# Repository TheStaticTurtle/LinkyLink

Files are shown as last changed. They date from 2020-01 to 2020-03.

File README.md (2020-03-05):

Everyone want's to see how much power you are actually using, This product is a wireless adapter for the french energy meter (Linky). It's based on an esp8266 which convert the raw data coming from the tele-info port on the linky and displays it in a web page. It also exposes an API for easy integration with a smart home dashboard like home-assistant.

## Disclaimer
- If you don't wire it up correctly or break anything I'm not responsible for any damage that might occur.
- Moreover, you will need a separate power source, unfortunately the alimentation loop isn't powerful enough
## The product
See the datasheet for the installation manual
#### Why did I make it?
I'm a student in computer sciences so I was interested to see how I could decode it and make it more understandable for less technical people and at the same time improve my electrical engineering skill.

#### What makes it special?
It's small and wireless, not everyone wants a big cable running from their meter to their home automation server. It has a beautiful interface:
Phone interface
Tablet interface

It's very easy to set up, just connect it to the linky, power it up, connect to its wifi enter the connection detail to your wifi and voila.
**But most importantly it's realtime no waiting for the values to change and you don't have to send all your information to enedis/edf**

#### What's included
Depending on the options you will get the board and a case and ~30cm of cable to connect it to the linky

#### Support
If you need support (eg. firmware update/error) just send me an email at tuglersamuel@gmail.com

- Hardware License: CERN v 1.2
- Software License: GPL v3
- Documentation License: CC BY

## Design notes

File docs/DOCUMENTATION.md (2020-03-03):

# A bit of context.
Linky energy meter
Teleinfo port

The Linky energy meter is "connected" energy meter it transmit the energy consumed by their user to the energy comany (Enedis).

## The inners workings
The arrow on the second picture above show the user teleinfo port. Here the user is free to plug something like the "Linky ERL" or any device to monitor the meter.


The linky provides 3 "easy" to use ports I1 I2 and A. 
The actual data comes from the circuit I1 and I2 and you have an alimentation circuit between I1 and A. For reference P, N, P', N' are the mains connections C1 and C2 connection to a water boiler and T1 / T2 are I think for technicians and are locked.

The actual signal is a unidirectional serial connection with a 50kHz carrier. The documentation (availible at the bottom) sais that the signal is at 9600bps 7E1  but the signal is accualy 1200bps at 7E1.
Converting this signal is really simple I used the following circuit:

The linky spits out frames composed of these lines (For the one I have):
```
ADCO 341964285263
OPTARIF HC..
ISOUSC 30
HCHC 000582078
HCHP 000599002
PTEC HP..
IINST 005
IMAX 090
PAPP 01115
HHPHC A
MOTDETAT 000000
```
Here's a table to see what stands for what:



# Version 1 - Prototype
The documentation tells us how a frame is transmitted: 
First you have the char 0x02 ther for each line start 0x0A and 0x0D the the end of a line the end of a frame is signaled by the char 0x03 and a premature end of data by 0x04

```cpp
#define LINKY_START_FRAME           0x02
#define LINKY_END_FRAME             0x03
#define LINKY_START_LINE            0x0A
#define LINKY_END_LINE              0x0D
#define LINKY_END_DATA              0x04
```
As I wanted to make my module compatible with 3-phased devices I added all these in the code as well and here's my structure for holding the data:
```cpp
struct LinkyData {
  char   ADCO   [13];      //Adresse du compteur
  char   OPTARIF[ 5];      //Option tarifaire choisie
  int    ISOUSC;           //Intensité souscrite
  int    BASE;             //Index option Base
  long   HCHC;             //Index option Heures Creuses - Heures Creuses
  long   HCHP;             //Index option Heures Creuses - Heures Pleines
  long   EJPHN;            //Index option EJP - Heures Normales
  long   EJPHPM;           //Index option EJP - Heures de Pointe Mobile
  long   BBRHCJB;          //Index option Tempo - Heures Creuses Jours Bleus
  long   BBRHPJB;          //Index option Tempo - Heures Pleines Jours Bleus
  long   BBRHCJW;          //Index option Tempo - Heures Creuses Jours Blancs
  long   BBRHPJW;          //Index option Tempo - Heures Pleines Jours Blancs
  long   BBRHCJR;          //Index option Tempo - Heures Pleines Jours Rouges
  long   BBRHPJR;          //Index option Tempo - Heures Pleines Jours Rouges
  int    PEJP;             //Préavis Début EJP (30 min)
  char   PTEC   [ 5];      //Période Tarifaire en cours
  char   DEMAIN [ 5];      //Couleur du lendemain
  int    IINST;            //Intensité Instantanée
  int    IINST1;           //Intensité Instantanée Phase n°1 (Triphaser seulement)
  int    IINST2;           //Intensité Instantanée Phase n°2 (Triphaser seulement)
  int    IINST3;           //Intensité Instantanée Phase n°3 (Triphaser seulement)
  int    ADPS;             //Avertissement de DépassementDe Puissance Souscrite
  int    ADIR1;            //Avertissement de DépassementDe Puissance Souscrite Phase n°1 (Triphaser seulement)
  int    ADIR2;            //Avertissement de DépassementDe Puissance Souscrite Phase n°2 (Triphaser seulement)
  int    ADIR3;            //Avertissement de DépassementDe Puissance Souscrite Phase n°3 (Triphaser seulement)
  int    IMAX;             //Intensité maximale appelée
  int    IMAX1;            //Intensité maximale appelée Phase n°1 (Triphaser seulement)
  int    IMAX2;            //Intensité maximale appelée Phase n°2 (Triphaser seulement)
  int    IMAX3;            //Intensité maximale appelée Phase n°3 (Triphaser seulement)
  long   PMAX;             //Puissance maximale triphasée atteinte
  long   PAPP;             //Puissance apparente / Puissance apparente triphasée soutirée
  char   HHPHC;            //Horaire Heures Pleines Heures Creuses
  char   MOTDETAT[ 7];     //Mot d'état du compteur
  char   PPOT    [ 3];     //Présence des potentiels (Triphaser seulement) ("0X", X = coupures de phase phase n => bit n = 1)
}; 
```

Receiving the data is as simple as creating a new software serial with the right pins and AND the incoming byte by 0x7F to get only the 7 bits since arduino softwareserial can't stricly do 7E1 communications. Then I created a char array of the size of 100 (It will never be used completly) and incremented a variable a each valid char received to store it.

```cpp
void Linky::processRXChar(char currentChar) {
	if(currentChar == LINKY_START_FRAME) {
		memset(_buffer, 0, LINKY_BUFFER_TELEINFO_SIZE);
		_bufferIterator = 0;

	} else if(currentChar == LINKY_START_LINE) {
		memset(_buffer, 0, LINKY_BUFFER_TELEINFO_SIZE);
		_bufferIterator = 0;

	} else if(currentChar == LINKY_END_FRAME) {
		memset(_buffer, 0, LINKY_BUFFER_TELEINFO_SIZE);
		_bufferIterator = 0;

	} else if(currentChar == LINKY_END_LINE) {
		updateStruct(_bufferIterator);
		memset(_buffer, 0, LINKY_BUFFER_TELEINFO_SIZE);
		_bufferIterator = 0;

	} else if(currentChar == LINKY_END_DATA) {
		memset(_buffer, 0, LINKY_BUFFER_TELEINFO_SIZE);
		_bufferIterator = 0;

	} else {
		_buffer[_bufferIterator] = currentChar;
		_bufferIterator++;

	}
}
void Linky::updateAsync() {
	if(_serport->available()) {
		char currentChar;

		currentChar = _serport->read() & 0x7F;
		processRXChar(currentChar);
	}
}
```
Then I created a couple of function that ease the parsing of the data by a lot (getCommandValue_int / getCommandValue_long / getCommandValue_str) to use these function you have to pass the actual command name like ADCO the length in this case 4 and the expcted length of the output in this case 12 plus some other values like the size of received line.
```cpp
bool Linky::isValidNumber(String str){
   for(byte i=0;i<str.length();i++)  {
       if(!isDigit(str.charAt(i))) return false;
   }
   return true;
}

int Linky::getCommandValue_int(String CMD, int CMDlenght, int CMDResultLenght, String line, int lineLenght, int defaultIfError) {
  if(!line.startsWith(CMD)) { return defaultIfError; }
  if(CMDlenght+1+CMDResultLenght > lineLenght) { return defaultIfError; } // Invalid size line length too short
  
  String raw_value = line.substring(CMDlenght+1, CMDlenght+1+CMDResultLenght);
  if(!isValidNumber(raw_value)) { return defaultIfError; }
  
  return raw_value.toInt();
}

long Linky::getCommandValue_long(String CMD, int CMDlenght, int CMDResultLenght, String line, int lineLenght, long defaultIfError) {
  if(!line.startsWith(CMD)) { return defaultIfError; }
  if(CMDlenght+1+CMDResultLenght > lineLenght) { return defaultIfError; } // Invalid size line length too short
  
  String raw_value = line.substring(CMDlenght+1, CMDlenght+1+CMDResultLenght);
  if(!isValidNumber(raw_value)) { return defaultIfError; }
  
  return (long)raw_value.toInt();
}

bool Linky::getCommandValue_str(String CMD, int CMDlenght, int CMDResultLenght, String line, int lineLenght, char* value) {
  if(!line.startsWith(CMD)) { return false; }
  if(CMDlenght+1+CMDResultLenght > lineLenght) { return false; } // Invalid size line length too short
  
  line.substring(CMDlenght+1, CMDlenght+1+CMDResultLenght).toCharArray(value,CMDResultLenght+1);
  return true;
} 

void Linky::updateStruct(int len) {
	 getCommandValue_str ("ADCO"    , 4,12,_buffer,len+1, _data.ADCO     );
	 getCommandValue_str ("OPTARIF" , 7, 4,_buffer,len+1, _data.OPTARIF  );
	_data.ISOUSC 	=	getCommandValue_int ("ISOUSC"  , 6, 2,_buffer,len+1, _data.ISOUSC);
	_data.HCHC   	=	getCommandValue_long("HCHC"    , 4, 9,_buffer,len+1, _data.HCHC);
	_data.HCHP   	=	getCommandValue_long("HCHP"    , 4, 9,_buffer,len+1, _data.HCHP);
	_data.EJPHN  	=	getCommandValue_long("EJPHN"   , 5, 9,_buffer,len+1, _data.EJPHN);
	_data.EJPHPM 	=	getCommandValue_long("EJPHPM"  , 6, 9,_buffer,len+1, _data.EJPHPM);
	_data.BBRHCJB	=	getCommandValue_long("BBRHCJB" , 7, 9,_buffer,len+1, _data.BBRHCJB);
	_data.BBRHPJB	=	getCommandValue_long("BBRHPJB" , 7, 9,_buffer,len+1, _data.BBRHPJB);
	_data.BBRHCJW	=	getCommandValue_long("BBRHCJW" , 7, 9,_buffer,len+1, _data.BBRHCJW);
	_data.BBRHPJW	=	getCommandValue_long("BBRHPJW" , 7, 9,_buffer,len+1, _data.BBRHPJW);
	_data.BBRHCJR	=	getCommandValue_long("BBRHCJR" , 7, 9,_buffer,len+1, _data.BBRHCJR);
	_data.BBRHPJR	=	getCommandValue_long("BBRHPJR" , 7, 9,_buffer,len+1, _data.BBRHPJR);
	_data.PEJP   	=	getCommandValue_int ("PEJP"    , 4, 2,_buffer,len+1, _data.HCHP);
 	 getCommandValue_str ("PTEC"    , 4, 4,_buffer,len+1, _data.PTEC  );
     getCommandValue_str ("DEMAIN"  , 6, 4,_buffer,len+1, _data.DEMAIN  );
	_data.IINST     = 	getCommandValue_int ("IINST"   , 5, 3,_buffer,len+1, _data.IINST); 
	_data.IINST1    = 	getCommandValue_int ("IINST1"  , 6, 3,_buffer,len+1, _data.IINST1); 
	_data.IINST2    = 	getCommandValue_int ("IINST2"  , 6, 3,_buffer,len+1, _data.IINST2); 
	_data.IINST3    = 	getCommandValue_int ("IINST3"  , 6, 3,_buffer,len+1, _data.IINST3); 
	_data.ADPS      = 	getCommandValue_int ("ADPS"    , 4, 3,_buffer,len+1, _data.ADPS); 
	_data.ADIR1     = 	getCommandValue_int ("ADIR1"   , 5, 3,_buffer,len+1, _data.ADIR1); 
	_data.ADIR2     = 	getCommandValue_int ("ADIR2"   , 5, 3,_buffer,len+1, _data.ADIR2); 
	_data.ADIR3     = 	getCommandValue_int ("ADIR3"   , 5, 3,_buffer,len+1, _data.ADIR3);
	_data.IMAX      = 	getCommandValue_int ("IMAX"    , 4, 3,_buffer,len+1, _data.IMAX); 
	_data.IMAX1     = 	getCommandValue_int ("IMAX1"   , 5, 3,_buffer,len+1, _data.IMAX1); 
	_data.IMAX2     = 	getCommandValue_int ("IMAX2"   , 5, 3,_buffer,len+1, _data.IMAX2); 
	_data.IMAX3     = 	getCommandValue_int ("IMAX3"   , 5, 3,_buffer,len+1, _data.IMAX3); 
	_data.PMAX      = 	getCommandValue_long("PMAX"    , 4, 5,_buffer,len+1, _data.PMAX); 
	_data.PAPP      = 	getCommandValue_long("PAPP"    , 4, 5,_buffer,len+1, _data.PAPP); 
	 getCommandValue_str ("MOTDETAT", 8, 6,_buffer,len+1, _data.MOTDETAT );
	 getCommandValue_str ("PPOT"    , 4, 2,_buffer,len+1, _data.PPOT);
}
```

## Implementing everything into the ESP8266
**Needs writing**

## PCB Desing
**Needs writing**

## Assembly
**Needs writing**

## Finished product
**Needs writing**

## Sources:
[Enedis documentation](https://www.enedis.fr/sites/default/files/Enedis-NOI-CPT_54E.pdf)

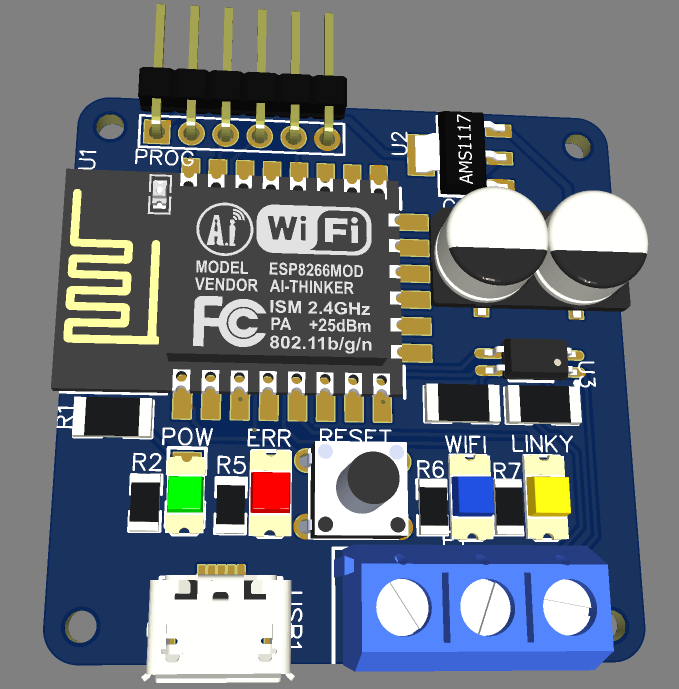
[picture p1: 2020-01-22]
hardware/renderV1.png

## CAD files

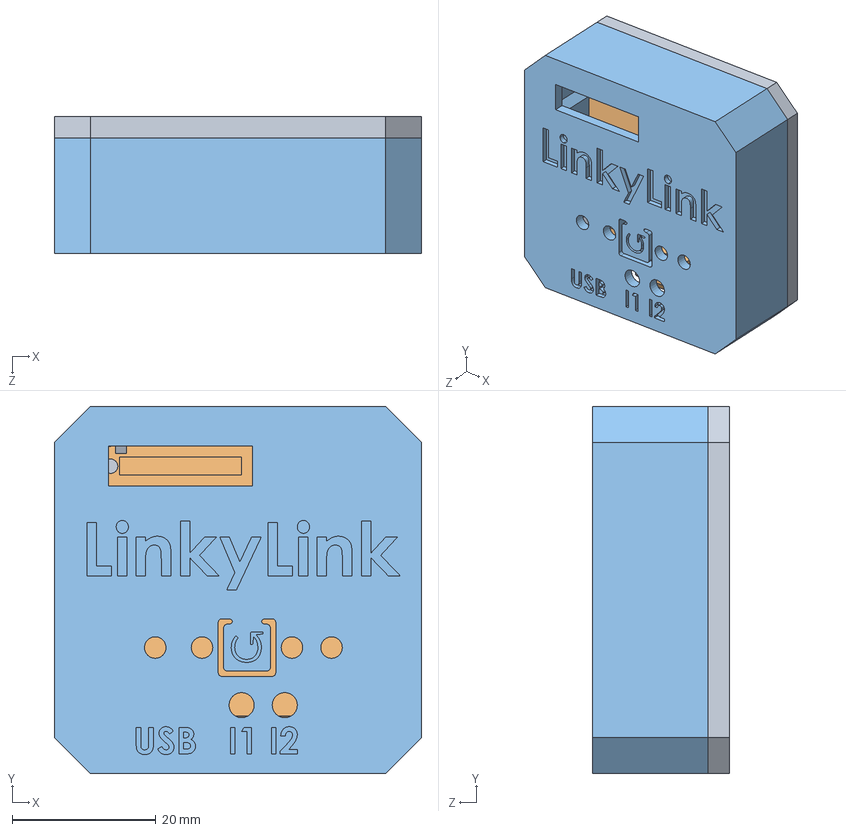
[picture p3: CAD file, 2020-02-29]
hardware/3d/Assemblage2.SLDASM
51.0 x 51.0 x 19.0 mm
basev2
pcb
Pièce5^Assemblage2

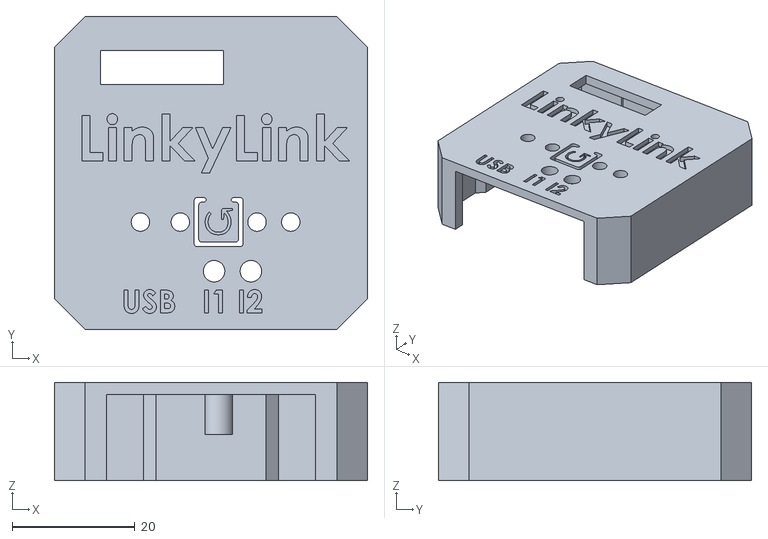
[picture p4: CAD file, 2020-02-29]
hardware/3d/Stls/Assemblage2 - Pièce5^Assemblage2-1-1.STL
51.0 x 51.0 x 16.0

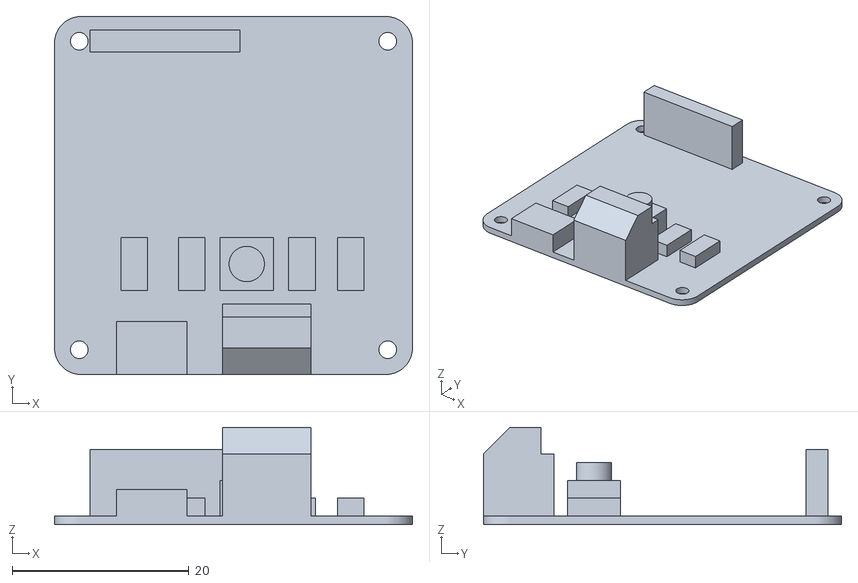
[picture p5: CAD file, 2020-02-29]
hardware/3d/Stls/Assemblage2 - pcb-1.STL
40.5 x 40.5 x 11.0

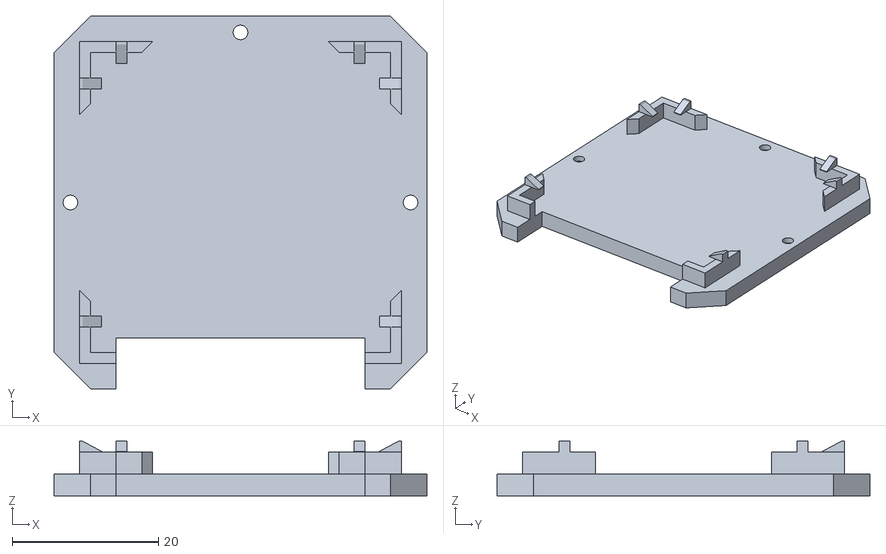
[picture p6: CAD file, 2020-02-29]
hardware/3d/Stls/Assemblage2 - basev2-1-1.STL
51.0 x 51.0 x 7.50

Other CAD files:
hardware/3d/Stls/Assemblage2 - basev2-1.STL
hardware/3d/Stls/Assemblage2 - Pièce5^Assemblage2-1.STL
hardware/3d/basev2.SLDPRT
hardware/3d/pcb.SLDPRT

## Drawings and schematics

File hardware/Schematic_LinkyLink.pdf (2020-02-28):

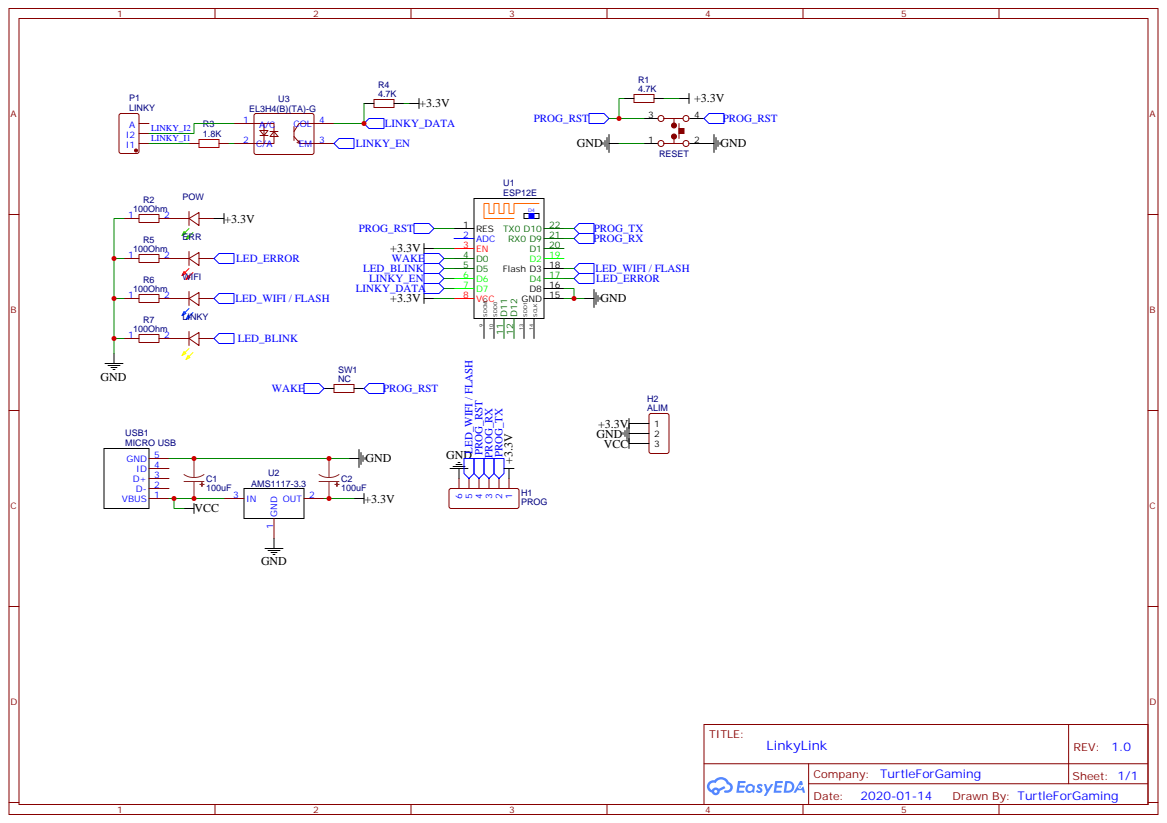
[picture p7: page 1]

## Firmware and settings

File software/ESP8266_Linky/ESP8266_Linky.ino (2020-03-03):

#include <FS.h>                   //this needs to be first, or it all crashes and burns...
#include <ESP8266WiFi.h>
#include <DNSServer.h>
#include <ESPAsyncTCP.h>
#include <ESPAsyncWebServer.h>
#include <ESPAsyncWiFiManager.h>
#include <ArduinoJson.h>
#include <ESP8266mDNS.h>
#include <ArduinoOTA.h>
#include <WiFiUdp.h>
#include <Ticker.h>
#include <SPIFFSLogger.h>

#include "linky.h"

const char* MODULE_SERIAL_NUM   = "LinkyLinky-00001";
const char* MODULE_VERSION_SOFT = "V1.0";
const char* MODULE_VERSION_HARD = "V1.0";

const int   PINS_LED_STATUS_WIFI = D3;
const int   PINS_LED_STATUS_LINK = D5;
const int   PINS_LED_STATUS_ERR  = D4;
const int   PINS_CTRL_DATA_IN    = D6;
const int   LOGGING_INTERVAL     = 10000;
const int   LOGGING_DAY_KEPT     = 1;
const char* LOGGING_FOLDER       = "/log/linkydata";

 
Linky mLinky(D7,-1,PINS_CTRL_DATA_IN);
AsyncWebServer server(80);
DNSServer dns;
Ticker tickerWifiLed;

long lastRequestCounter = 0;
bool shouldReEnableListingToLinky = false;

const size_t ApiJsonTemplate_capacity = JSON_OBJECT_SIZE(31) + 310;

struct LoggingData {
	long PAPP;
};

SPIFFSLogger<LoggingData> logger(LOGGING_FOLDER, LOGGING_DAY_KEPT);


void handleAPI_Reboot(AsyncWebServerRequest *request) {
	Serial.println("[WEB] Serving 200 for: /api/reboot");
	Serial.flush();

	AsyncResponseStream *response = request->beginResponseStream("plain/text");
	response->addHeader("Access-Control-Allow-Methods", "POST,GET,OPTIONS");
	response->addHeader("Access-Control-Allow-Headers", "Origin, X-Requested-With, Content-Type, Accept");
	response->addHeader("Access-Control-Allow-Origin", "*");
	response->printf("REBOOTING");
	request->send(response);

	ESP.restart();
	lastRequestCounter = millis();
	shouldReEnableListingToLinky = true;
}

void handleAPI_Info(AsyncWebServerRequest *request) {
	Serial.println("[WEB] Serving 200 for: /api/info");
	Serial.flush();
	AsyncResponseStream *response = request->beginResponseStream("application/json");
	response->addHeader("Access-Control-Allow-Methods", "POST,GET,OPTIONS");
	response->addHeader("Access-Control-Allow-Headers", "Origin, X-Requested-With, Content-Type, Accept");
	response->addHeader("Access-Control-Allow-Origin", "*");
	
	StaticJsonDocument<200> doc;
	doc["serial_number"]    = MODULE_SERIAL_NUM;
	doc["version_software"] = MODULE_VERSION_SOFT;
	doc["version_hardware"] = MODULE_VERSION_HARD;
	doc["uptime"]           = millis() / 1000;
	doc["lastUpdate"]       = mLinky.lastFullFrame() /1000;
	
	serializeJson(doc, *response);

	request->send(response);
	lastRequestCounter = millis();
	shouldReEnableListingToLinky = true;
}

void handleAPI_Debug(AsyncWebServerRequest *request) {
	Serial.println("[WEB] Serving 200 for: /api/debug");
	Serial.flush();
	AsyncResponseStream *response = request->beginResponseStream("application/json");
	response->addHeader("Access-Control-Allow-Methods", "POST,GET,OPTIONS");
	response->addHeader("Access-Control-Allow-Headers", "Origin, X-Requested-With, Content-Type, Accept");
	response->addHeader("Access-Control-Allow-Origin", "*");
	
	StaticJsonDocument<200> doc;
	doc["serial_number"]     = MODULE_SERIAL_NUM;
	doc["version_software"]  = MODULE_VERSION_SOFT;
	doc["version_hardware"]  = MODULE_VERSION_HARD;
	doc["uptime"]            = millis() / 1000;
	doc["lastUpdate"]        = mLinky.lastFullFrame() /1000;
	doc["wifi_status"]       = WiFi.status();
	doc["wifi_macaddr"]      = WiFi.macAddress();
	doc["free_heap"]         = ESP.getFreeHeap();
	doc["max_block_size"]    = ESP.getMaxFreeBlockSize();
	doc["last_reset_cause"]  = ESP.getResetReason();
	doc["core_version"]      = ESP.getCoreVersion();
	doc["vcc"]               = ESP.getVcc();
	
	serializeJson(doc, *response);

	request->send(response);
	lastRequestCounter = millis();
	shouldReEnableListingToLinky = true;
}

void handleAPI_Linky(AsyncWebServerRequest *request) {
	Serial.println("[WEB] Serving 200 for: /api/linky");
	Serial.flush();

	LinkyData linkyData = mLinky.grab();

	if(request->hasParam("key")) {
		AsyncWebParameter* p = request->getParam("key");
		String output = F("Key is invalid");
		if(p->value() == "ADCO"    ) { output = linkyData.ADCO;    }   
		if(p->value() == "OPTARIF" ) { output = linkyData.OPTARIF; }      
		if(p->value() == "ISOUSC"  ) { output = linkyData.ISOUSC;  }     
		if(p->value() == "HCHC"    ) { output = linkyData.HCHC;    }   
		if(p->value() == "HCHP"    ) { output = linkyData.HCHP;    }   
		if(p->value() == "EJPHN"   ) { output = linkyData.EJPHN;   }    
		if(p->value() == "EJPHPM"  ) { output = linkyData.EJPHPM;  }     
		if(p->value() == "BBRHCJB" ) { output = linkyData.BBRHCJB; }      
		if(p->value() == "BBRHPJB" ) { output = linkyData.BBRHPJB; }      
		if(p->value() == "BBRHCJW" ) { output = linkyData.BBRHCJW; }      
		if(p->value() == "BBRHPJW" ) { output = linkyData.BBRHPJW; }      
		if(p->value() == "BBRHCJR" ) { output = linkyData.BBRHCJR; }      
		if(p->value() == "BBRHPJR" ) { output = linkyData.BBRHPJR; }      
		if(p->value() == "PEJP"    ) { output = linkyData.PEJP;    }   
		if(p->value() == "PTEC"    ) { output = linkyData.PTEC;    }   
		if(p->value() == "DEMAIN"  ) { output = linkyData.DEMAIN;  }     
		if(p->value() == "IINST"   ) { output = linkyData.IINST;   }    
		if(p->value() == "IINST1"  ) { output = linkyData.IINST1;  }     
		if(p->value() == "IINST2"  ) { output = linkyData.IINST2;  }     
		if(p->value() == "IINST3"  ) { output = linkyData.IINST3;  }     
		if(p->value() == "ADPS"    ) { output = linkyData.ADPS;    }   
		if(p->value() == "ADIR1"   ) { output = linkyData.ADIR1;   }    
		if(p->value() == "ADIR2"   ) { output = linkyData.ADIR2;   }    
		if(p->value() == "ADIR3"   ) { output = linkyData.ADIR3;   }    
		if(p->value() == "IMAX"    ) { output = linkyData.IMAX;    }
		if(p->value() == "IMAX1"   ) { output = linkyData.IMAX1;   }
		if(p->value() == "IMAX2"   ) { output = linkyData.IMAX2;   }
		if(p->value() == "IMAX3"   ) { output = linkyData.IMAX3;   }    
		if(p->value() == "PMAX"    ) { output = linkyData.PMAX;    }
		if(p->value() == "PAPP"    ) { output = linkyData.PAPP;    }
		if(p->value() == "HHPHC"   ) { output = linkyData.HHPHC;   }
		if(p->value() == "MOTDETAT") { output = linkyData.MOTDETAT;   }
		if(p->value() == "PPOT"    ) { output = linkyData.PPOT;   }

		AsyncWebServerResponse *response = request->beginResponse(200,"text/plain",output);
		response->addHeader("Access-Control-Allow-Methods", "POST,GET,OPTIONS");
		response->addHeader("Access-Control-Allow-Headers", "Origin, X-Requested-With, Content-Type, Accept");
		response->addHeader("Access-Control-Allow-Origin", "*");
		request->send(response);

	} else {
		DynamicJsonDocument ApiJsonTemplate_doc(ApiJsonTemplate_capacity);
		ApiJsonTemplate_doc["ADCO"    ] = linkyData.ADCO;
		ApiJsonTemplate_doc["OPTARIF" ] = linkyData.OPTARIF;
		ApiJsonTemplate_doc["ISOUSC"  ] = linkyData.ISOUSC;
		ApiJsonTemplate_doc["HCHC"    ] = linkyData.HCHC;
		ApiJsonTemplate_doc["HCHP"    ] = linkyData.HCHP;
		ApiJsonTemplate_doc["EJPHN"   ] = linkyData.EJPHN;
		ApiJsonTemplate_doc["EJPHPM"  ] = linkyData.EJPHPM;
		ApiJsonTemplate_doc["BBRHCJB" ] = linkyData.BBRHCJB;
		ApiJsonTemplate_doc["BBRHPJB" ] = linkyData.BBRHPJB;
		ApiJsonTemplate_doc["BBRHCJW" ] = linkyData.BBRHCJW;
		ApiJsonTemplate_doc["BBRHPJW" ] = linkyData.BBRHPJW;
		ApiJsonTemplate_doc["BBRHCJR" ] = linkyData.BBRHCJR;
		ApiJsonTemplate_doc["BBRHPJR" ] = linkyData.BBRHPJR;
		ApiJsonTemplate_doc["PEJP"    ] = linkyData.PEJP;
		ApiJsonTemplate_doc["PTEC"    ] = linkyData.PTEC;
		ApiJsonTemplate_doc["DEMAIN"  ] = linkyData.DEMAIN;
		ApiJsonTemplate_doc["IINST"   ] = linkyData.IINST;
		ApiJsonTemplate_doc["IINST1"  ] = linkyData.IINST1;
		ApiJsonTemplate_doc["IINST2"  ] = linkyData.IINST2;
		ApiJsonTemplate_doc["IINST3"  ] = linkyData.IINST3;
		ApiJsonTemplate_doc["ADPS"    ] = linkyData.ADPS;
		ApiJsonTemplate_doc["ADIR1"   ] = linkyData.ADIR1;
		ApiJsonTemplate_doc["ADIR2"   ] = linkyData.ADIR2;
		ApiJsonTemplate_doc["ADIR3"   ] = linkyData.ADIR3;
		ApiJsonTemplate_doc["IMAX"    ] = linkyData.IMAX;
		ApiJsonTemplate_doc["IMAX1"   ] = linkyData.IMAX1;
		ApiJsonTemplate_doc["IMAX2"   ] = linkyData.IMAX2;
		ApiJsonTemplate_doc["IMAX3"   ] = linkyData.IMAX3;
		ApiJsonTemplate_doc["PMAX"    ] = linkyData.PMAX;
		ApiJsonTemplate_doc["PAPP"    ] = linkyData.PAPP;
		ApiJsonTemplate_doc["HHPHC"   ] = linkyData.HHPHC;
		ApiJsonTemplate_doc["MOTDETAT"] = linkyData.MOTDETAT;
		ApiJsonTemplate_doc["PPOT"    ] = linkyData.PPOT;

		AsyncResponseStream *response = request->beginResponseStream("application/json");
		response->addHeader("Access-Control-Allow-Methods", "POST,GET,OPTIONS");
		response->addHeader("Access-Control-Allow-Headers", "Origin, X-Requested-With, Content-Type, Accept");
		response->addHeader("Access-Control-Allow-Origin", "*");
		serializeJson(ApiJsonTemplate_doc, *response);
		request->send(response);
	}

	lastRequestCounter = millis();
	shouldReEnableListingToLinky = true;
}

float max(float a, float b) {
	if( a > b ) { return a; }
	return b;
}

void pathFromDate(char *output, time_t date) {
    struct tm *tinfo = gmtime(&date);
    sprintf_P(output,
              "%s/%d%02d%02d",
              "/log/linkydata",
              1900 + tinfo->tm_year,
              tinfo->tm_mon + 1,
              tinfo->tm_mday);
}

void handleAPI_History(AsyncWebServerRequest *request) {
	digitalWrite(PINS_CTRL_DATA_IN,true);
	Serial.println("[WEB] Serving 200 for: /api/history");
	Serial.flush();

	const time_t todayTime = time(nullptr);
	const time_t yesterday = todayTime - 3600 * 24;
	const size_t rowCountY = logger.rowCount(yesterday);
	const size_t rowCountT = logger.rowCount(todayTime);

	struct SPIFFSLogData<LoggingData> readback;

	AsyncResponseStream *response = request->beginResponseStream("text/plain");
	response->addHeader("Access-Control-Allow-Methods", "POST,GET,OPTIONS");
	response->addHeader("Access-Control-Allow-Headers", "Origin, X-Requested-With, Content-Type, Accept");
	response->addHeader("Access-Control-Allow-Origin", "*");

	//RESPONSE V2 - Optimized - Fast re-implementation of SPIFFSLogger read for this use case (Mainly not opening and closing the file at each read)
	int count = 1111;
	float step = (float)(rowCountY+rowCountT) / (float)count;
	time_t begin_time = 0;
	time_t end_time = 0;

	response->printf("{\"data\":[");

	unsigned long valuesSmoothSum = 0;
	int valuesCount = 0;
	float counter = 0;


    size_t size = sizeof(SPIFFSLogData<LoggingData>);
	char path[32];
	pathFromDate(path,yesterday);
	if(SPIFFS.exists(path)) {
    	File f = SPIFFS.open(path, "r");

		for(int i=0; i <  rowCountY ; i++ ) {
		    f.seek(i * size);
		    f.read((uint8_t *)&readback , size);


			if(i == 0) { begin_time = readback.timestampUTC; }
			end_time = readback.timestampUTC;
			valuesSmoothSum += readback.data.PAPP;
			valuesCount ++;

			counter ++;

			if(counter > step) {
				response->printf("%lu,", (valuesSmoothSum / valuesCount) );
				valuesSmoothSum = readback.data.PAPP;
				valuesCount = 1;
				counter-=step;
			}

		}
		f.close();
	}

	pathFromDate(path,todayTime);
	if(SPIFFS.exists(path)) {
    	File f = SPIFFS.open(path, "r");

		for(int i=0; i <  rowCountT ; i++ ) {
		    f.seek(i * size);
		    f.read((uint8_t *)&readback , size);

			if(i == 0 && begin_time == 0) { begin_time = readback.timestampUTC; }
			end_time = readback.timestampUTC;
			valuesSmoothSum += readback.data.PAPP;
			valuesCount ++;

			counter ++;

			if(counter > step) {
				response->printf("%lu,", (valuesSmoothSum / valuesCount) );
				valuesSmoothSum = readback.data.PAPP;
				valuesCount = 1;
				counter-=step;
			}
		}
		f.close();
	}

	response->printf("], \"db_value_count\": %d,\"result_steps\": %f, \"begin_time\": %lu, \"end_time\": %lu}",(rowCountY+rowCountT),step,begin_time,end_time);

	request->send(response);

	lastRequestCounter = millis();
	shouldReEnableListingToLinky = true;
}

void sendFileToServer(char* filename, AsyncWebServerRequest *request) {
	digitalWrite(PINS_CTRL_DATA_IN,true);

	Serial.println("[WEB] Serving 200 for url: "+request->url());
	Serial.flush();

	AsyncWebServerResponse *response = request->beginResponse(SPIFFS, filename);
	
	response->addHeader("Access-Control-Allow-Methods", "POST,GET,OPTIONS");
	response->addHeader("Access-Control-Allow-Headers", "Origin, X-Requested-With, Content-Type, Accept");
	response->addHeader("Access-Control-Allow-Origin", "*");

	request->send(response);
	lastRequestCounter = millis();
	shouldReEnableListingToLinky = true;
	//digitalWrite(PINS_CTRL_DATA_IN,false);
}

void handleNotFound( AsyncWebServerRequest *request) {
	digitalWrite(PINS_CTRL_DATA_IN,true);
	Serial.println("[WEB] Serving 404 for url: "+request->url());
	Serial.flush();
	request->send(404, "text/plain", "File "+request->url()+" not found");
	lastRequestCounter = millis();
	shouldReEnableListingToLinky = true;
	//digitalWrite(PINS_CTRL_DATA_IN,false);
}

void tickWifiLed() {
  int state = digitalRead(PINS_LED_STATUS_WIFI);  // get the current state of GPIO1 pin
  digitalWrite(PINS_LED_STATUS_WIFI, !state);     // set pin to the opposite state
}

void configModeCallback (AsyncWiFiManager *myWiFiManager) {
  tickerWifiLed.attach(0.1, tickWifiLed);
}


void setup() {
	pinMode(PINS_LED_STATUS_ERR ,OUTPUT);
	pinMode(PINS_LED_STATUS_LINK,OUTPUT);
	pinMode(PINS_LED_STATUS_WIFI,OUTPUT);
	pinMode(PINS_CTRL_DATA_IN   ,OUTPUT);
	digitalWrite(PINS_LED_STATUS_ERR ,true);
	digitalWrite(PINS_LED_STATUS_LINK,true);
	digitalWrite(PINS_LED_STATUS_WIFI,true);
	digitalWrite(PINS_CTRL_DATA_IN   ,true);
	delay(100);
	digitalWrite(PINS_LED_STATUS_ERR ,false);
	digitalWrite(PINS_LED_STATUS_LINK,false);
	digitalWrite(PINS_LED_STATUS_WIFI,true);
	digitalWrite(PINS_CTRL_DATA_IN   ,false);



	Serial.begin(115200);
	Serial.println();
	Serial.println();
	Serial.println("Booting up....");
	
	SPIFFS.begin();

	logger.init();
	
	Dir dir = SPIFFS.openDir("/");
	Serial.println("[SPIFFS] Files in memory: ");
	while (dir.next()) { Serial.print("\t"); Serial.print(dir.fileName());  Serial.print(" / "); Serial.println(dir.fileSize()); }

	tickerWifiLed.attach(0.6, tickWifiLed);

	AsyncWiFiManager wifiManager(&server,&dns);
	
	wifiManager.setAPCallback(configModeCallback);
	wifiManager.setConfigPortalTimeout(60*10);

	WiFi.hostname(MODULE_SERIAL_NUM);

	if (!wifiManager.autoConnect(MODULE_SERIAL_NUM, "LinkyLinkSetup")) {
		Serial.println("[WiFi] Failed to connect and hit timeout");
		digitalWrite(PINS_LED_STATUS_ERR ,true);
		ESP.reset(); delay(1000);
	}
	tickerWifiLed.detach();
	digitalWrite(PINS_LED_STATUS_WIFI, true);

	Serial.print("[WiFi] IP Address: ");
	Serial.println(WiFi.localIP());

	configTime(0, 0, "pool.ntp.org");

	if (MDNS.begin("LinkyLink")) { Serial.println("[MDNS] Begin ok"); } else  { Serial.println("[MDNS] Begin failed"); }
	
	server.on("/"                 , HTTP_GET, [](AsyncWebServerRequest *request){ sendFileToServer("/www/index.html"       ,request); });
	server.on("/logo.svg"         , HTTP_GET, [](AsyncWebServerRequest *request){ sendFileToServer("/www/logo.svg"         ,request); });
	server.on("/fa-solid-900.ttf" , HTTP_GET, [](AsyncWebServerRequest *request){ sendFileToServer("/www/fa-solid-900.ttf" ,request); });
	server.on("/js.js"            , HTTP_GET, [](AsyncWebServerRequest *request){ sendFileToServer("/www/js.js"            ,request); });
	server.on("/css.css"          , HTTP_GET, [](AsyncWebServerRequest *request){ sendFileToServer("/www/css.css"          ,request); });
	server.on("/favicon.png"      , HTTP_GET, [](AsyncWebServerRequest *request){ sendFileToServer("/www/favicon.png"      ,request); });
	server.on("/api/linky"        , HTTP_GET, handleAPI_Linky);

	server.on("/api/info"         , HTTP_GET, handleAPI_Info);
	server.on("/api/debug"        , HTTP_GET, handleAPI_Debug);
	server.on("/api/history"      , HTTP_GET, handleAPI_History);
	server.on("/api/reboot"      , HTTP_GET, handleAPI_Reboot);
	server.onNotFound(handleNotFound);

	server.begin();

	Serial.println(F("[WEB] Begin"));

	ArduinoOTA.setHostname("LinkyLink");
	// ArduinoOTA.setPassword("admin");

	ArduinoOTA.onStart([]() {
		String type;
		if (ArduinoOTA.getCommand() == U_FLASH) { type = "sketch"; } 
		else { type = "filesystem"; }
		Serial.println("[OTA] Start updating " + type);
	});
	ArduinoOTA.onEnd([]() {  Serial.println("\nEnd"); });
	ArduinoOTA.onProgress([](unsigned int progress, unsigned int total) { Serial.printf("[OTA] Progress: %u%%\r", (progress / (total / 100))); });
	ArduinoOTA.onError([](ota_error_t error) {
		Serial.printf("[OTA] Error[%u]: ", error);
		if (error == OTA_AUTH_ERROR) {
			Serial.println("[OTA] Auth Failed");
		} else if (error == OTA_BEGIN_ERROR) {
			Serial.println("[OTA] Begin Failed");
		} else if (error == OTA_CONNECT_ERROR) {
			Serial.println("[OTA] Connect Failed");
		} else if (error == OTA_RECEIVE_ERROR) {
			Serial.println("[OTA] Receive Failed");
		} else if (error == OTA_END_ERROR) {
			Serial.println("[OTA] End Failed");
		}
	});
	ArduinoOTA.begin();
	Serial.println(F("[OTA] Begin"));

	mLinky.begin();
	Serial.println(F("LinkyLink V1 is in the place"));
}

#ifdef DEBUG
	void dumpStruct(LinkyData linkyData) {
		Serial.print(F("[LINKY] Data dump incomming"));
		Serial.print(F("[LINKY] linkyData.ADCO     => ")); Serial.println(linkyData.ADCO);
		Serial.print(F("[LINKY] linkyData.OPTARIF  => ")); Serial.println(linkyData.OPTARIF);
		Serial.print(F("[LINKY] linkyData.ISOUSC   => ")); Serial.println(linkyData.ISOUSC);
		Serial.print(F("[LINKY] linkyData.HCHC     => ")); Serial.println(linkyData.HCHC);
		Serial.print(F("[LINKY] linkyData.HCHP     => ")); Serial.println(linkyData.HCHP);
		Serial.print(F("[LINKY] linkyData.EJPHN    => ")); Serial.println(linkyData.EJPHN);
		Serial.print(F("[LINKY] linkyData.EJPHPM   => ")); Serial.println(linkyData.EJPHPM);
		Serial.print(F("[LINKY] linkyData.BBRHCJB  => ")); Serial.println(linkyData.BBRHCJB);
		Serial.print(F("[LINKY] linkyData.BBRHPJB  => ")); Serial.println(linkyData.BBRHPJB);
		Serial.print(F("[LINKY] linkyData.BBRHCJW  => ")); Serial.println(linkyData.BBRHCJW);
		Serial.print(F("[LINKY] linkyData.BBRHPJW  => ")); Serial.println(linkyData.BBRHPJW);
		Serial.print(F("[LINKY] linkyData.BBRHCJR  => ")); Serial.println(linkyData.BBRHCJR);
		Serial.print(F("[LINKY] linkyData.BBRHPJR  => ")); Serial.println(linkyData.BBRHPJR);
		Serial.print(F("[LINKY] linkyData.PEJP     => ")); Serial.println(linkyData.PEJP);
		Serial.print(F("[LINKY] linkyData.PTEC     => ")); Serial.println(linkyData.PTEC);
		Serial.print(F("[LINKY] linkyData.DEMAIN   => ")); Serial.println(linkyData.DEMAIN);
		Serial.print(F("[LINKY] linkyData.IINST    => ")); Serial.println(linkyData.IINST);
		Serial.print(F("[LINKY] linkyData.IINST1   => ")); Serial.println(linkyData.IINST1);
		Serial.print(F("[LINKY] linkyData.IINST2   => ")); Serial.println(linkyData.IINST2);
		Serial.print(F("[LINKY] linkyData.IINST3   => ")); Serial.println(linkyData.IINST3);
		Serial.print(F("[LINKY] linkyData.ADPS     => ")); Serial.println(linkyData.ADPS);
		Serial.print(F("[LINKY] linkyData.ADIR1    => ")); Serial.println(linkyData.ADIR1);
		Serial.print(F("[LINKY] linkyData.ADIR2    => ")); Serial.println(linkyData.ADIR2);
		Serial.print(F("[LINKY] linkyData.ADIR3    => ")); Serial.println(linkyData.ADIR3);
		Serial.print(F("[LINKY] linkyData.IMAX     => ")); Serial.println(linkyData.IMAX);
		Serial.print(F("[LINKY] linkyData.IMAX1    => ")); Serial.println(linkyData.IMAX1);
		Serial.print(F("[LINKY] linkyData.IMAX2    => ")); Serial.println(linkyData.IMAX2);
		Serial.print(F("[LINKY] linkyData.IMAX3    => ")); Serial.println(linkyData.IMAX3);
		Serial.print(F("[LINKY] linkyData.PMAX     => ")); Serial.println(linkyData.PMAX);
		Serial.print(F("[LINKY] linkyData.PAPP     => ")); Serial.println(linkyData.PAPP);
		Serial.print(F("[LINKY] linkyData.HHPHC    => ")); Serial.println(linkyData.HHPHC);
		Serial.print(F("[LINKY] linkyData.MOTDETA  => ")); Serial.println(linkyData.MOTDETAT);
		Serial.print(F("[LINKY] linkyData.PPOT     => ")); Serial.println(linkyData.PPOT);
		Serial.println();
		Serial.println();
	}
#endif

unsigned long lastLog = 0;
time_t  _filenameToDate(const char *filename) {
    struct tm tm = {0};
    char datePart[5] = {0};
    strncpy(datePart, filename, 4);
    tm.tm_year = atoi(datePart) - 1900;
    strncpy(datePart, filename + 4, 2);
    datePart[2] = '\0';
    tm.tm_mon = atoi(datePart) - 1;
    strncpy(datePart, filename + 6, 2);
    tm.tm_mday = atoi(datePart);
    return _timegm(&tm) / 86400 * 86400;
}
time_t _timegm(struct tm *tm) {
    struct tm start2000 = { 0,  0,  0, 1,  0,  100, 0, 0, 0,  };
    return mktime(tm) - (mktime(&start2000) - 946684800);
}
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
void loop() {
	ArduinoOTA.handle();
	if( mLinky.updateAsync(PINS_LED_STATUS_LINK,true) ) {
		Serial.println("[LINKY] Got frame");
	}

	if(((lastRequestCounter + 30000) < millis()) && shouldReEnableListingToLinky){
		shouldReEnableListingToLinky = false;
		digitalWrite(PINS_CTRL_DATA_IN,false);
		Serial.println("[LINKY] Restoring connection");
	} 
	
	#ifdef DEBUG
		LinkyData data = mLinky.grab();
		dumpStruct(data);
	#endif

	if(digitalRead(PINS_CTRL_DATA_IN) == false) {
		if (millis() - lastLog > LOGGING_INTERVAL) {
			mLinky.waitEndMessage();
			digitalWrite(PINS_CTRL_DATA_IN,true);
			Serial.println("[DB] Proccesing values");

			LinkyData linkyData = mLinky.grab();
			struct LoggingData data;

			if(mLinky.lastFullFrame() > 10000) {
				data.PAPP = 0;
			} else {
				data.PAPP = linkyData.PAPP;
			}

			logger.write(data);
			lastLog = millis();

			clearingOldLogFiles();
			logger.process();

			digitalWrite(PINS_CTRL_DATA_IN,false);
			mLinky.waitEndMessage();
			Serial.println("[DB] Done");
		}
	}
}

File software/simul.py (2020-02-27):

import time
import serial

# configure the serial connections (the parameters differs on the device you are connecting to)
ser = serial.Serial(
    port='COM29',
    baudrate=1200,
    parity=serial.PARITY_ODD,
    stopbits=serial.STOPBITS_ONE,
    bytesize=serial.SEVENBITS
)

ser.isOpen()

ser.write(chr(0x02))
ser.write(chr(0x0A) + "ADCO ABCDEFGHIJKLM" + chr(0x0D))
ser.write(chr(0x0A) + "PAPP 00900" + chr(0x0D))
ser.write(chr(0x03))
ser.write(chr(0x02))
ser.write(chr(0x0A) + "ADCO ABCDEFGHIJKLM" + chr(0x0D))
ser.write(chr(0x0A) + "PAPP 00900" + chr(0x0D))
ser.write(chr(0x03))
ser.write(chr(0x02))
ser.write(chr(0x0A) + "ADCO ABCDEFGHIJKLM" + chr(0x0D))
ser.write(chr(0x0A) + "PAPP 00900" + chr(0x0D))
ser.write(chr(0x03))

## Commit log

2020-01-22 Added plain text search for the api + status leds
2020-01-22 Added first real "good" pcb
    [Gerber_BoardOutline.GKO, Gerber_BottomLayer.GBL, Gerber_BottomSolderMaskLayer.GBS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]
2020-02-27 Added graphic of the consumption + Added debug function + Correct some bugs + Added favicon + Modifed webpage
    [ESP8266_Linky.ino, linky.cpp, simul.py]
2020-02-27 Created a simple enclosure
    [Assemblage2 - Pièce5^Assemblage2-1.STL, Assemblage2 - basev2-1.STL, Assemblage2.SLDASM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]
2020-02-28 Corrected some bugs / created the documentation / latest pcb - schematic
    [Gerber_BoardOutline.GKO, Gerber_BottomLayer.GBL, Gerber_BottomSolderMaskLayer.GBS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]
